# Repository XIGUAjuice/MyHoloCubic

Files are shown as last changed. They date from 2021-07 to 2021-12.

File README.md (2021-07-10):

<h1 align="center"> HoloCubic--多功能透明显示屏桌面站</h1>
<p align="center">
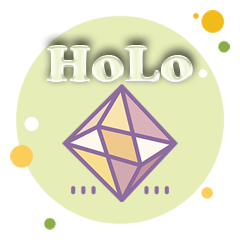
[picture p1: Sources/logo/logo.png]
 
</p>

## 项目说明

- 原项目地址: https://github.com/peng-zhihui/HoloCubic
- 原项目视频介绍: https://www.bilibili.com/video/BV1VA411p7MD
- 该项目基于稚辉君的项目，使用了一块分光棱镜来改变屏幕光线光路，实现了伪全息的显示效果。本项目显示设备实现了时钟、闹钟、实时天气显示、天气预报显示、多城市天气预报显示、扫码配网等功能。

<p align="center">
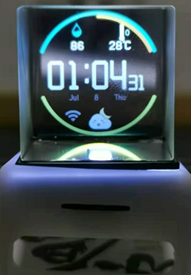
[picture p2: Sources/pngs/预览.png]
 
</p>

## 文件结构

```
MyCubic
├─ Circuit      电路原理图、PCB图
├─ Code         软件代码，Platformio项目文件
├─ Documents    可供查阅的文档资料
├─ Model        外壳3d打印文件
├─ Simulator    模拟器，Platformio项目文件
├─ Sources      原始图像、字体资源
├─ bin          这个文件夹需放入Sd卡中
└─ README.md
```

## 硬件打样

本项目里的电路原理图和PCB图是我参照稚辉君的电路图自己绘制的，主要是想从头走一遍这样的流程：元器件选型--元器件手册阅读--原理图绘制--PCB绘制。这是我第一个项目，以前没有接触过这些，所以自己练习了一遍，因此可能存在瑕疵。大家可以使用原项目仓库中的PCB文件进行打样，我使用了同样的引脚，所以软件代码是通用的。
> 如果使用原仓库的PCB，EN引脚的0.1uF电容需替换为1uF电容，使得下载时的上电顺序稳定，否则可能出现下载不稳定的情况

## 软件编译

软件代码基于Arduino框架，我使用VSCode的PlatformIO进行开发，有关PlatformIO请访问 https://platformio.org/platformio-ide

此外，需注意以下三点：

- esp32-pico-d4的引导程序和SD卡的IO脚存在冲突，GPIO12在上电复位时需下拉为0，让内部稳压器给板载的Flash提供3.3V电压。解决方式有两种
  - 一种是进入 `.platformio\packages\tool-esptoolpy` 文件夹然后运行以下命令，此命令将烧毁XPD_SDIO_TIEH、XPD_SDIO_FORCE和XPD_SDIO_REG 三个熔丝，内部 VDD_SDIO flash 稳压器将永久设置为 3.3 V。（不可逆）
    ``` 
    components/esptool_py/esptool/espefuse.py set_flash_voltage 3.3V 
    ```
  - 另一种是使用ESP32的GPIO交换矩阵，把这个IO口的功能转移到其它IO口上。进入`.platformio\packages\framework-arduinoespressif32\libraries\SPI\src\SPI.cpp`文件中，将以下代码中的12改为26。（会降低SPI最大速率）
    ```
      if(sck == -1 && miso == -1 && mosi == -1 && ss == -1) {
        _sck = (_spi_num == VSPI) ? SCK : 14;
        _miso = (_spi_num == VSPI) ? MISO : 12; // 需要改为26
        _mosi = (_spi_num == VSPI) ? MOSI : 13;
        _ss = (_spi_num == VSPI) ? SS : 15;
     ```
- 在 `include\network.h` 文件中定义自己的WEBKEY，本项目使用了高德开放平台的API，可以去 https://lbs.amap.com/ 免费申请
- 需要将整个`bin`文件夹放入Sd卡中

## LVGL模拟器

`Simulator`为模拟器项目文件夹，可以在windows上模拟TFT屏幕，方便控件的布局，不用每次都下载代码。在PlatformIO上使用模拟器需要安装`SDL`，请参考 https://github.com/lvgl/lv_platformio

## 3d打印外壳

3d模型我在稚辉君的模型作了一点修改，将两部分合成一部分，扩大了TypeC的口，原版口太小了，我的TypeC没法完全插入。

关于装配，棱镜与屏幕可以使用`UV胶`进行粘接，屏幕板和外壳之间可以用`热熔胶`封口固定

## 操作说明

<p align="center">
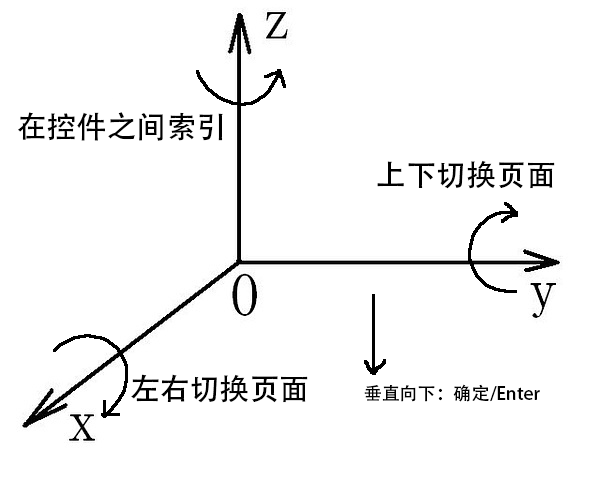
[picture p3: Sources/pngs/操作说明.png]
 
</p>

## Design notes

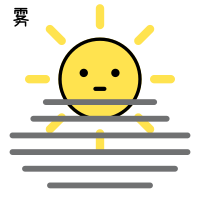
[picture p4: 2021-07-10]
Sources/pngs/23qingtianwu.png

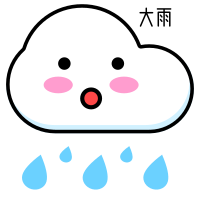
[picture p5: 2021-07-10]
Sources/pngs/13dayu.png

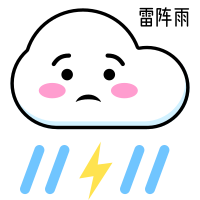
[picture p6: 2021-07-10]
Sources/pngs/8leizhenyu.png

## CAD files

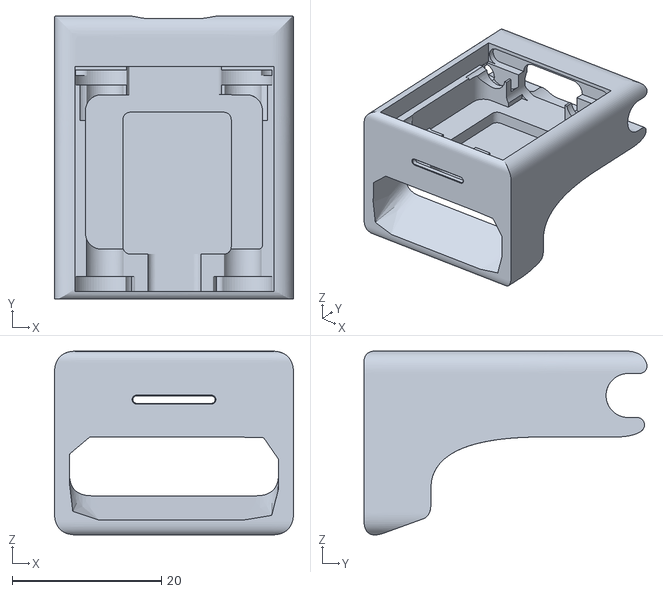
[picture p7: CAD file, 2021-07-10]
Model/shell.stl
32.0 x 37.9 x 24.6

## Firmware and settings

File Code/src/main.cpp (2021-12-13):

#include <TFT_eSPI.h>
#include <lvgl.h>
#include "lv_port_fatfs.h"
#include "sd_card.h"
#include "network.h"
#include "home_page.h"
#include "setting_page.h"
#include "wifi_page.h"
#include "input_device_mpu.h"
#include "fresh_task.h"
#include "lv_init.h"
#include "smartconfig_page.h"
#include "page_alarm.h"
#include "weather_page.h"
#include "cityweather.h"

SdCard sd;
Network net;
InputDevice indev;
lv_obj_t * bar1;

void setup()
{
    /* 打开串口 */
    Serial.begin(115200);

    /* LVGL初始化 */
    initLvgl();

    /* SD卡初始化 */
    Serial.println("初始化SD卡...");
    sd.init();

    /* 显示Logo */
    lv_obj_t *img_logo = lv_img_create(lv_scr_act(), NULL);
    lv_img_set_src(img_logo, "S:/bin/logo.bin");

    /* 启动lvgl的线程 */
    xTaskCreate(freshLvgl, "lvgl", 20480, NULL, 24, &task_lvgl);

    /* 显示进度条 */
    bar1 = lv_bar_create(lv_scr_act(), NULL);
    lv_obj_set_size(bar1, 200, 20);
    lv_obj_align(bar1, NULL, LV_ALIGN_CENTER, 0, 100);
    lv_bar_set_anim_time(bar1, 2000);
    lv_bar_set_range(bar1, 0, 3);
    lv_bar_set_value(bar1, 1, LV_ANIM_ON);

    /* 自动连接上次的WiFi */
    net.connectWifiLast();
    lv_bar_set_value(bar1, 2, LV_ANIM_ON);

    /* 初始化陀螺仪 */
    indev.mpuInit();
    lv_bar_set_value(bar1, 3, LV_ANIM_ON);
    delay(2000);
    vTaskSuspend(task_lvgl);
    delay(1500);
    
    /* 创建UI */
    Serial.println("创建UI...");
    createTile();             //创建磁贴
    createPageHome();         //创建主页面
    createPageSetting();      // 创建设置页面
    createPageWifiSetting();  //创建WiFi设置界面
    createPageSmartConfig();  // 创建扫码页面
    createPageAlarm();        // 创建闹钟页面
    createPageAlarmSetting(); // 创建闹钟设置页面
    createPageWeather();      // 创建城市天气页面
    // 创建天气预报页面
    display_temperature_chart();
    display_temperature_label();
    display_weather_icon();

    vTaskResume(task_lvgl);

    /* 初始化输入设备 */
    Serial.println("初始化输入设备...");
    indev.inputDriveInit();

    /* 创建任务 */
    createTasks(); // 创建LVGL任务
}

void loop()
{
}

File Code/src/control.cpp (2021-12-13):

#include <control.h>

lv_obj_t *tile_main;
lv_obj_t *page_home;
lv_obj_t *page_weather;
lv_obj_t *page_setting;
lv_obj_t *page_setting_wifi;
lv_obj_t *drop_wifi;
lv_obj_t *text_area_pwd;
lv_obj_t *keyboard;
lv_obj_t *btn_scan;
lv_obj_t *btn_connect;

lv_obj_t *img_wifi;
LV_IMG_DECLARE(base_face);

lv_obj_t *roller_time[5];
lv_obj_t *cont_time;

lv_obj_t *label_time;

lv_obj_t *cont_date;
lv_obj_t *label_date[3];

lv_obj_t *img_weather;
lv_obj_t *img_temp;
lv_obj_t *label_temp;
lv_obj_t *label_humidity;

lv_obj_t *page_smart_config;
lv_obj_t *spinner_smart_config;
lv_obj_t *img_ok;

lv_obj_t *page_alarm;
lv_obj_t *page_alarm_setting;

/* 磁贴回调函数 */
static void tile_event_cb(lv_obj_t *obj, lv_event_t event)
{
    switch (event)
    {
    case LV_EVENT_KEY:
        uint32_t *key = (uint32_t *)lv_event_get_data();
        lv_coord_t x, y;
        static bool wifi_in_group = false;
        static bool smart_config_start = false;
        static bool alarm_in_group = false;

        /*************************** 控制页面切换 ***************************/
        lv_tileview_get_tile_act(tile_main, &x, &y); //获取当前页面坐标
        if (*key == LV_KEY_DOWN)
        {
            /* 向下切换页面 */
            lv_tileview_set_tile_act(tile_main, x, y + 1, LV_ANIM_ON);
        }
        else if (*key == LV_KEY_UP)
        {
            /* 向上切换页面 */
            lv_tileview_set_tile_act(tile_main, x, y - 1, LV_ANIM_ON);
        }
        else if (*key == LV_KEY_RIGHT)
        {
            /* 向右切换页面 */
            lv_tileview_set_tile_act(tile_main, x + 1, y, LV_ANIM_ON);
        }
        else if (*key == LV_KEY_LEFT)
        {
            /* 向左切换页面 */
            lv_tileview_set_tile_act(tile_main, x - 1, y, LV_ANIM_ON);
        }

        /************************** 控制特殊页面的事件 ****************************/

        // 在WiFi设置页面将各个控件加入控制组
        lv_tileview_get_tile_act(tile_main, &x, &y); //获取当前页面坐标

        if (x == 1 && y == 1 && !wifi_in_group)
        {
            Serial.println("将Wifi相关控件加入控制组");
            lv_group_add_obj(group_tile, drop_wifi);
            lv_group_add_obj(group_tile, btn_connect);
            lv_group_add_obj(group_tile, btn_scan);
            lv_group_add_obj(group_tile, text_area_pwd);
            wifi_in_group = true;
        }
        // 退出WiFi设置页面后将各个控件移出控制组
        else if ((x != 1 || y != 1) && wifi_in_group)
        {
            Serial.println("将Wifi相关控件移出控制组");
            lv_group_remove_obj(drop_wifi);
            lv_group_remove_obj(btn_connect);
            lv_group_remove_obj(btn_scan);
            lv_group_remove_obj(text_area_pwd);
            wifi_in_group = false;
        }

        // 在闹钟设置页面将roller加入控制组
        if (x == 1 && y == 2 && !alarm_in_group)
        {
            Serial.println("将闹钟相关控件加入控制组");
            for (int i = 0; i < 5; i++)
            {
                if (i != 2)
                    lv_group_add_obj(group_tile, roller_alarm[i]);
            }
            alarm_in_group = true;

            // 在设置闹钟期间关闭闹钟
            Serial.println("暂时关闭闹钟功能");
            my_alarm.alarmEnable(false);
        }
        // 退出闹钟设置页面后将roller移出控制组
        else if ((x != 1 || y != 2) && alarm_in_group)
        {
            Serial.println("将闹钟相关控件移出控制组");
            for (int i = 0; i < 5; i++)
            {
                if (i != 2)
                    lv_group_add_obj(group_tile, roller_alarm[i]);
            }
            alarm_in_group = false;

            // 重新打开闹钟功能
            Serial.println("打开闹钟功能");
            my_alarm.alarmEnable(true);

            // 将设置的闹钟时间写入
            my_alarm.setAlarm(roller_alarm);
        }

        // 在闹钟响时，任意动作打断闹钟
        if (my_alarm.getAlarmOn())
        {
            my_alarm.stopAlarm();
        }

        // 在扫码配网页面打开SmartConfig以及启用相关task
        if (x == 2 && y == 1 && !smart_config_start)
        {
            Serial.println("开启SmartConfig");
            smart_config_start = true;
            WiFi.beginSmartConfig();
        }
        // 退出扫码配网页面后关闭SmartConfig以及关闭相关task
        else if ((x != 2 || y != 1) && smart_config_start)
        {
            Serial.println("关闭SmartConfig");
            smart_config_start = false;
            WiFi.stopSmartConfig();
        }
        break;
    }
}

void createTile()
{
    // 设置磁贴样式
    static lv_style_t style_tile;
    lv_style_init(&style_tile);
    lv_style_set_bg_opa(&style_tile, 0, 0); // 取消背景

    // 创建磁贴模块
    tile_main = lv_tileview_create(lv_scr_act(), NULL);

    // 设置可达区域
    static lv_point_t valid_pos[] = {{0, 0}, {1, 0}, {2, 0}, {0, 1}, {1, 1}, {2, 1}, {0, 2}, {1, 2}};
    lv_tileview_set_valid_positions(tile_main, valid_pos, 8);
    // static lv_point_t valid_pos[] = {{0, 0}};
    // lv_tileview_set_valid_positions(tile_main, valid_pos, 1);
    // 设置边缘特效
    lv_tileview_set_edge_flash(tile_main, true);

    // 应用磁贴样式，取消滚动条
    lv_obj_add_style(tile_main, LV_TILEVIEW_PART_SCROLLBAR, &style_tile);

    // 设置磁贴回调函数
    lv_obj_set_event_cb(tile_main, tile_event_cb);

    // 创建主页面
    page_home = lv_obj_create(tile_main, NULL);
    lv_obj_set_size(page_home, LV_HOR_RES, LV_VER_RES);     //调整为整个屏幕大小
    lv_obj_set_style_local_border_side(page_home, 0, 0, 0); // 取消边框
    lv_tileview_add_element(tile_main, page_home);          //将主页面固定至磁贴
    // 设置背景为黑色
    lv_obj_set_style_local_bg_color(page_home, LV_OBJ_PART_MAIN, LV_STATE_DEFAULT, LV_COLOR_BLACK);
    // 取消圆角
    lv_obj_set_style_local_radius(page_home, LV_OBJ_PART_MAIN, LV_STATE_DEFAULT, 0);
    // 设置字体为白色
    lv_obj_set_style_local_text_color(page_home, LV_OBJ_PART_MAIN, LV_STATE_DEFAULT, LV_COLOR_WHITE);

    // 创建设置页面
    page_setting = lv_obj_create(tile_main, page_home);
    lv_obj_set_pos(page_setting, 0, LV_VER_RES);      // 位置为第二行，第一列
    lv_tileview_add_element(tile_main, page_setting); // 将设置页面固定至磁贴

    // 创建WiFi设置页面
    page_setting_wifi = lv_obj_create(tile_main, page_home);
    lv_obj_set_pos(page_setting_wifi, LV_HOR_RES, LV_VER_RES); // 位置为第二行，第二列
    lv_tileview_add_element(tile_main, page_setting_wifi);     // 将WiFi设置页面固定至磁贴

    // 创建扫码连接WiFi页面
    page_smart_config = lv_obj_create(tile_main, page_home);
    lv_obj_set_pos(page_smart_config, 2 * LV_HOR_RES, LV_VER_RES); // 位置为第二行，第三列
    lv_tileview_add_element(tile_main, page_smart_config);         // 将扫码页面固定至磁贴

    // 创建闹钟页面
    page_alarm = lv_obj_create(tile_main, page_home);
    lv_obj_set_pos(page_alarm, 0, 2 * LV_VER_RES);  // 位置为第三行，第一列
    lv_tileview_add_element(tile_main, page_alarm); // 将闹钟页面固定至磁贴

    // 创建闹钟设置页面
    page_alarm_setting = lv_obj_create(tile_main, page_home);
    lv_obj_set_pos(page_alarm_setting, LV_HOR_RES, 2 * LV_VER_RES); // 位置为第三行，第二列
    lv_tileview_add_element(tile_main, page_alarm_setting);         // 将闹钟设置页面固定至磁贴

    // 创建天气预报页面
    page_weather = lv_obj_create(tile_main, page_home);
    lv_obj_set_pos(page_weather, LV_HOR_RES, 0);      // 位置为第一行，第二列
    lv_tileview_add_element(tile_main, page_weather); // 将天气页面固定至磁贴
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

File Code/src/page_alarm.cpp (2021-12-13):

#include <page_alarm.h>

lv_obj_t *roller_alarm[5];
lv_obj_t *cont_alarm;
Alarm my_alarm;

void createPageAlarm()
{
    // 创建背景
    lv_obj_t *img_base = lv_img_create(page_alarm, NULL);
    lv_img_set_src(img_base, &base_face);

    // 创建闹钟图标
    lv_obj_t *img_alarm = lv_img_create(page_alarm, NULL);
    lv_img_set_src(img_alarm, "S:/bin/alarm.bin");               // 设置图标路径
    lv_obj_align(img_alarm, page_alarm, LV_ALIGN_CENTER, 0, 10); // 调整位置

    // 创建闹钟页面标题
    lv_obj_t *label_alarm = lv_label_create(page_alarm, NULL);
    lv_obj_set_style_local_text_font(label_alarm, 0, 0, &hanzi_25);     // 设置字体
    lv_label_set_text(label_alarm, "闹 钟");                            // 设置文本
    lv_obj_align(label_alarm, img_alarm, LV_ALIGN_OUT_TOP_MID, 0, -10); // 调整位置
}

/* roller的回调函数，当第一位为2时，第二位只能是0~3 (24小时格式) */
static void roller_alarm_cb(lv_obj_t *roller, lv_event_t event)
{
    if (event == LV_EVENT_KEY)
    {
        if (lv_roller_get_selected(roller) == 2)
        {
            lv_roller_set_options(roller_alarm[1], "0\n1\n2\n3", LV_ROLLER_MODE_INFINITE);
        }
        else
        {
            lv_roller_set_options(roller_alarm[1], "0\n1\n2\n3\n4\n5\n6\n7\n8\n9", LV_ROLLER_MODE_INFINITE);
        }
    }
}

void createPageAlarmSetting()
{
    static lv_style_t style_roller_alarm;
    lv_style_init(&style_roller_alarm);
    lv_style_set_shadow_color(&style_roller_alarm, LV_STATE_FOCUSED, LV_COLOR_RED);
    lv_style_set_shadow_width(&style_roller_alarm, LV_STATE_FOCUSED, 10);
    lv_style_set_shadow_spread(&style_roller_alarm, LV_STATE_FOCUSED, 3);

    // 创建roller的容器，从cont_time复制
    cont_alarm = lv_cont_create(page_alarm_setting, cont_time);

    // 创建5个roller显示数字，从roller_time复制
    for (int i = 0; i < 5; i++)
    {
        roller_alarm[i] = lv_roller_create(cont_alarm, roller_time[i]);

        // 应用roller样式
        lv_obj_add_style(roller_alarm[i], LV_ROLLER_PART_BG, &style_roller_alarm);

        // 修改选项
        if (i == 0)
        {
            // 第一位只有0~2
            lv_roller_set_options(roller_alarm[i], "0\n1\n2", LV_ROLLER_MODE_INFINITE);
            // 第二位可能是0~9，也可能是0~3
            lv_obj_set_event_cb(roller_alarm[i], roller_alarm_cb);
        }
        else if (i == 2)
        {
            // 第三位是冒号
            lv_roller_set_options(roller_alarm[i], ":", LV_ROLLER_MODE_INFINITE);
        }
        else if (i == 3)
        {
            // 第四位只有0~6
            lv_roller_set_options(roller_alarm[i], "0\n1\n2\n3\n4\n5", LV_ROLLER_MODE_INFINITE);
        }
        else
        {
            // 其他位为0~9
            lv_roller_set_options(roller_alarm[i], "0\n1\n2\n3\n4\n5\n6\n7\n8\n9", LV_ROLLER_MODE_INFINITE);
        }
    }
    lv_obj_align(cont_alarm, page_alarm_setting, LV_ALIGN_CENTER, 0, 0);

    my_alarm.init();                   // 初始化闹钟
    my_alarm.readFromSd(roller_alarm); // 读取闹钟设置
}

void Alarm::init()
{
    Serial.println("初始化Alarm");
    led.init();
    led.setBrightness(1);
    led.setColorBreath(50, 100, 50, 1, 2, 3);
}

void Alarm::checkAlarm(time_t time_now)
{
    int m = minute(time_now);
    if (m != prev_minute)
    {
        prev_minute = m;
        int h = hour(time_now);
        if (h == hour_set && m == min_set && alarm_enable)
        {
            Serial.println("闹钟设置时间到！");
            alarm_on = true;
        }
    }
}

void Alarm::setAlarm(lv_obj_t **roller_alarm)
{
    hour_set = lv_roller_get_selected(roller_alarm[0]) * 10 + lv_roller_get_selected(roller_alarm[1]);
    min_set = lv_roller_get_selected(roller_alarm[3]) * 10 + lv_roller_get_selected(roller_alarm[4]);

    // 将闹钟设置写入sd卡
    DynamicJsonDocument doc(50);
    doc["hour"] = hour_set;
    doc["minute"] = min_set;
    sd.writeJson("/alarm.json", doc);

    Serial.printf("闹钟设置为: %d : %d \n", hour_set, min_set);
}

/* 读取闹钟设置 */
void Alarm::readFromSd(lv_obj_t **roller_alarm)
{
    Serial.println("读取闹钟设置");
    DynamicJsonDocument doc(50);
    sd.readJson("/alarm.json", doc);
    int hour_set = doc["hour"];
    int min_set = doc["minute"];
    Serial.printf("读取闹钟设置为: %d : %d \n", hour_set, min_set);
    lv_roller_set_selected(roller_alarm[0], hour_set / 10, LV_ANIM_OFF);
    lv_roller_set_selected(roller_alarm[1], hour_set % 10, LV_ANIM_OFF);
    lv_roller_set_selected(roller_alarm[3], min_set / 10, LV_ANIM_OFF);
    lv_roller_set_selected(roller_alarm[4], min_set % 10, LV_ANIM_OFF);
}

bool Alarm::getAlarmOn()
{
    return alarm_on;
}

void Alarm::alarmBreathe()
{
    led.colorBreath();
}

void Alarm::stopAlarm()
{
    Serial.println("闹钟已关闭");
    led.setBrightness(0);
    alarm_on = false;
}

void Alarm::alarmEnable(bool enable)
{
    alarm_enable = enable;
}
